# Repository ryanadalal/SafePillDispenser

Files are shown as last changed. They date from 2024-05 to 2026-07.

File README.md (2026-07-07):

# Pill Safety Device

A smart medication dispensing system designed to promote safe, controlled, and responsible medication use. The device combines biometric authentication, scheduled dispensing, and caregiver controls to help ensure medication is taken only by authorized users and at the correct times.

## Overview

Medication adherence is important for both safety and treatment effectiveness. This project provides a secure medication dispenser that uses fingerprint authentication and a real-time clock to enforce dispensing schedules. Caregivers can manage the device through a built-in web interface, allowing them to configure settings, reload medication, and override restrictions when necessary.

The system is intended for situations where a user is capable of taking medication independently but still requires safeguards against missed doses, accidental overdoses, or unauthorized access.

### Features

* Fingerprint authentication to prevent unauthorized access.
* Time-based dispensing using a real-time clock.
* Audible alerts for missed doses and user feedback.
* Wi-Fi connectivity with a built-in web management interface.
* Caregiver override for fingerprint authentication and dispensing schedules.
* Weekly medication reloading and fingerprint management.

## Applications

Possible use cases include:

* Allowing older children to manage medication safely while remaining under caregiver supervision.
* Assisting elderly individuals with medication adherence while enabling caregivers to retain administrative control.
* Any application requiring controlled access to scheduled medication.

## Hardware

### Components

* ESP32 development board
* 2× servo motors
* R30x fingerprint sensor
* Real-time clock (RTC) module
* Arduino-compatible buzzer
* Push button
* Pull-down resistor
* 3D-printed enclosure and internal mechanisms (located in the `cadfiles` folder)

### Schematic

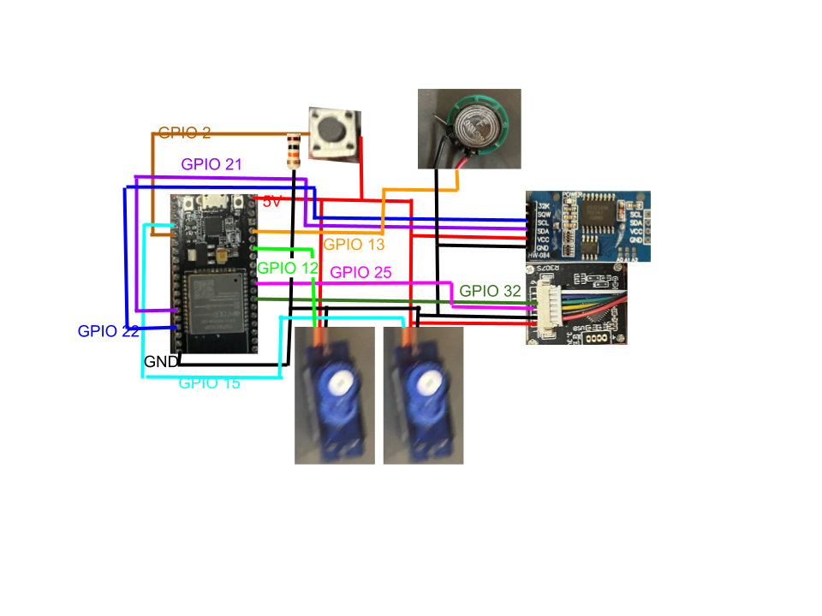
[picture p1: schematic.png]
schematic image


### Photos

#### Complete Assembly

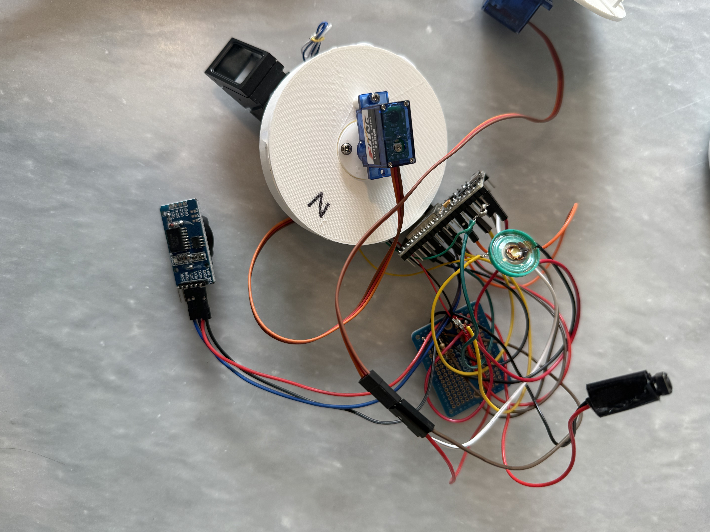
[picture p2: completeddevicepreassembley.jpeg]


#### Rotating Chamber with Integrated Fingerprint Sensor

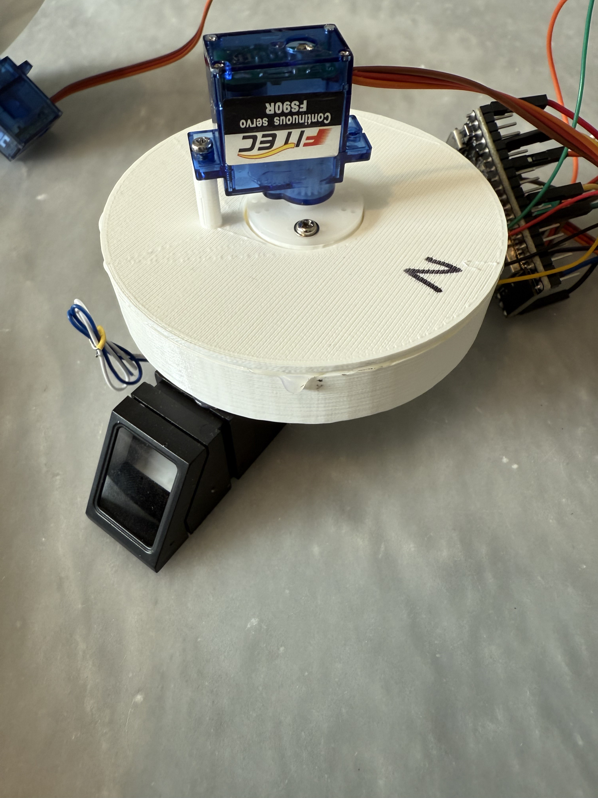
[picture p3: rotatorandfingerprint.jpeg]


#### Internal Sweeper Mechanism

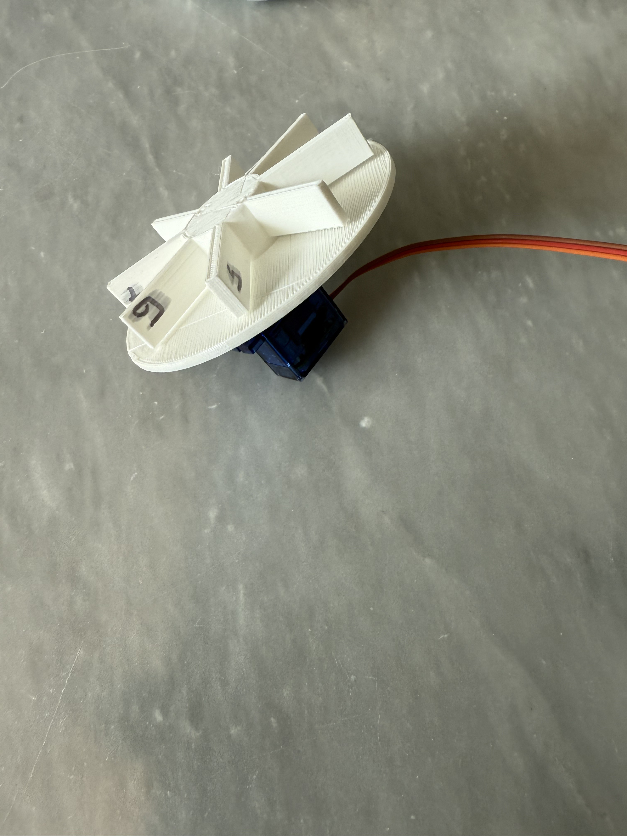
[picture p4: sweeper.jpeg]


## Software

### Project Structure

The primary application is located in:

```text
main/main.ino
```

### Libraries

The project uses the following libraries:

| Library | Purpose |
| --- | --- |
| FPM | Fingerprint sensor communication |
| RTClib | Real-time clock support |
| ESP32Servo | Servo motor control |
| WiFi | Wireless networking |
| ToneESP32 | Buzzer support |
| ESP32 Espressif Board Package | Hardware support and serial communication |

The fingerprint sensor implementation is based on:

https://github.com/brianrho/FPM

### Firmware Architecture

On startup, the ESP32 initializes the hardware peripherals and starts an HTTP server. Rather than serving a single static HTML page, the firmware generates and transmits each page in sections, simplifying maintenance and making it easier to add or modify interface components.

During normal operation, the web server remains largely inactive. User interaction is primarily driven by the push button, which initiates the fingerprint authentication process. Prioritizing local authentication requests ensures responsive dispensing while still allowing remote administration when required.

## Usage

### Normal Operation

1. Press the activation button.
2. Place a finger on the fingerprint sensor.
3. The device verifies the fingerprint.
4. If the authenticated user is a caregiver, dispensing restrictions can be overridden.
5. If the authenticated user is a patient, the firmware checks whether medication is scheduled for the current time.
6. If dispensing is permitted, the servo rotates the appropriate chamber and releases the medication.
7. Audible feedback indicates the result of the operation.

### Caregiver Functions

Using the web interface, a caregiver can:

* Configure device settings.
* Calibrate the dispensing mechanism.
* Reload a new week's supply of medication.
* Override dispensing restrictions when necessary.
* Register or reset caregiver and patient fingerprints.

## Future Improvements

Potential enhancements include:

* Mobile application for remote notifications and management.
* Secure user authentication for the web interface.
* Encrypted communication between the device and management interface.
* Medication logging and dispensing history.
* Battery backup for continued operation during power outages.
* Cloud synchronization and remote monitoring.
* Support for multiple patients or more complex medication schedules.

## License

This project is licensed under the **MIT License**.

Copyright (c) 2026 Ryan Dalal

Permission is hereby granted, free of charge, to any person obtaining a copy
of this software and associated documentation files (the "Software"), to deal
in the Software without restriction, including without limitation the rights
to use, copy, modify, merge, publish, distribute, sublicense, and/or sell
copies of the Software, and to permit persons to whom the Software is
furnished to do so, subject to the following conditions:

The above copyright notice and this permission notice shall be included in all
copies or substantial portions of the Software.

THE SOFTWARE IS PROVIDED "AS IS", WITHOUT WARRANTY OF ANY KIND, EXPRESS OR
IMPLIED, INCLUDING BUT NOT LIMITED TO THE WARRANTIES OF MERCHANTABILITY,
FITNESS FOR A PARTICULAR PURPOSE AND NONINFRINGEMENT. IN NO EVENT SHALL THE
AUTHORS OR COPYRIGHT HOLDERS BE LIABLE FOR ANY CLAIM, DAMAGES OR OTHER
LIABILITY, WHETHER IN AN ACTION OF CONTRACT, TORT OR OTHERWISE, ARISING FROM,
OUT OF OR IN CONNECTION WITH THE SOFTWARE OR THE USE OR OTHER DEALINGS IN THE
SOFTWARE.

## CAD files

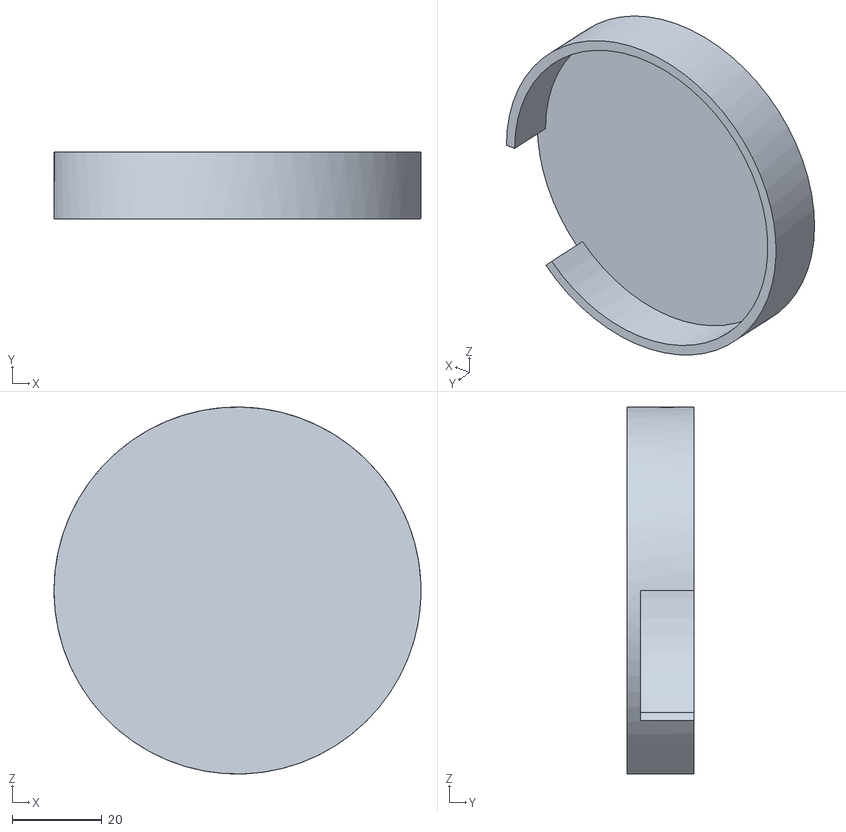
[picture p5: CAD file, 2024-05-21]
cadfiles/mainbody.stl
82.0 x 15.0 x 82.0

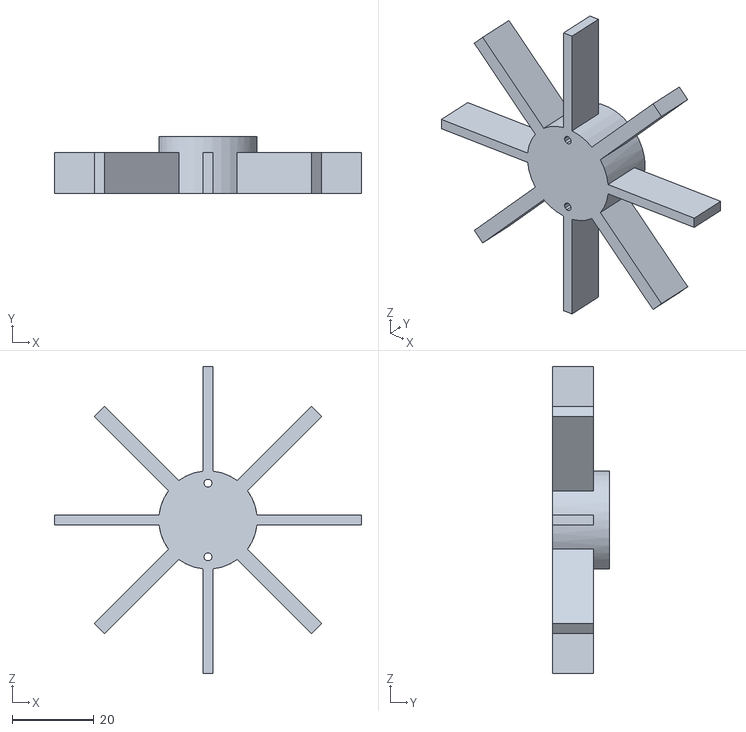
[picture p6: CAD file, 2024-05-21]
cadfiles/sweeper.stl
75.0 x 14.0 x 75.0

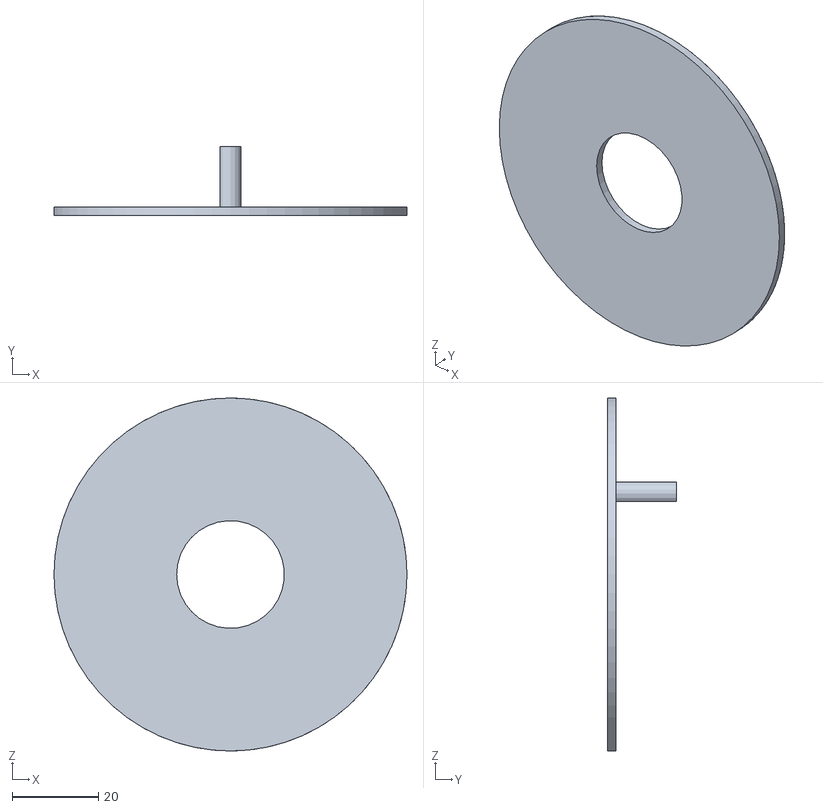
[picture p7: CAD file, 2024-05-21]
cadfiles/lidbetter.stl
82.0 x 16.0 x 82.0

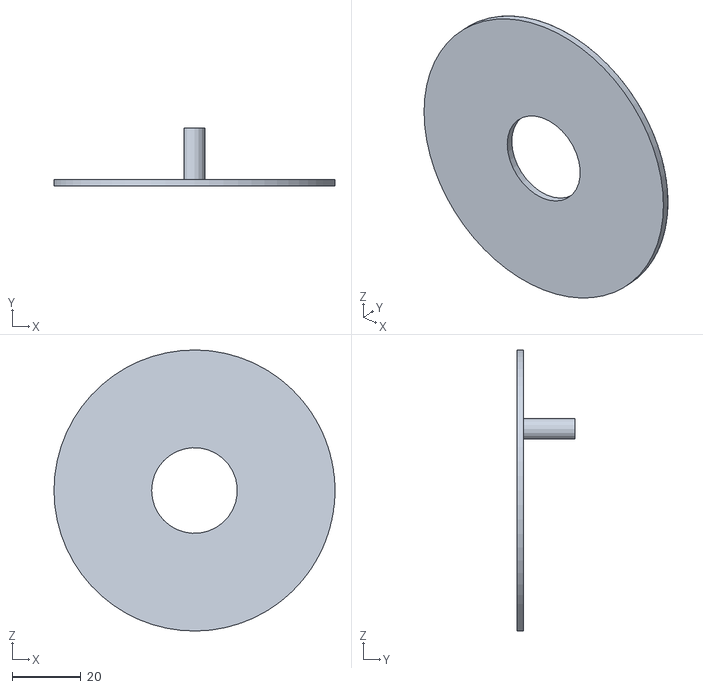
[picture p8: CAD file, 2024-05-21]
cadfiles/lid.stl
82.0 x 17.0 x 82.0

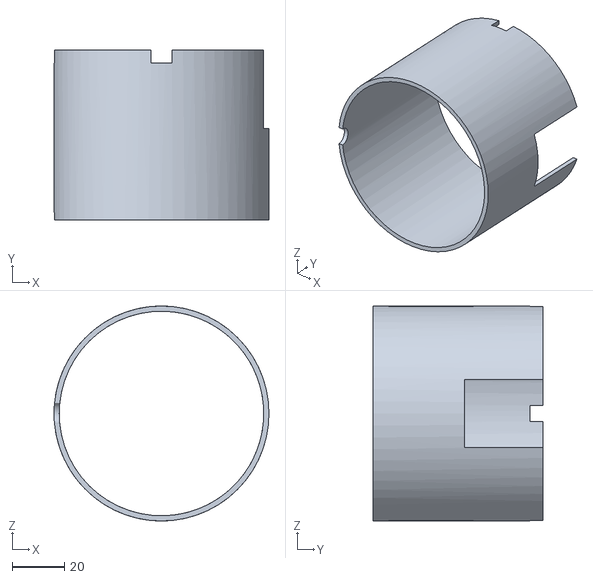
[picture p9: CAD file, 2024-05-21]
cadfiles/case.stl
82.0 x 65.0 x 82.0

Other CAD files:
cadfiles/OldVersions/case.0001.ipt
cadfiles/OldVersions/lid.0002.ipt
cadfiles/OldVersions/mainbody.0003.ipt
cadfiles/OldVersions/sweeper.0001.ipt
cadfiles/case.ipt
cadfiles/lid.ipt
cadfiles/lidbetter.ipt
cadfiles/mainbody.ipt
cadfiles/sweeper.ipt

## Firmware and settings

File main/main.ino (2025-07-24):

// comments designate arudion library manager names
#include <Wire.h>
#include <RTClib.h>         // rtclib
#include <ESP32Servo.h>     // esp32servo
#include <HardwareSerial.h> // esp espressif board
#include <fpm.h>            // FPM github
#include <WiFi.h>
#include <ToneESP32.h> // toneesp32

/*
In assembling the physical device:
- clock uses pins 21 and 22
- servo uses pin 15 and 0
- finger print uses pins 25 TX, 32 RX
- speaker red uses pin 13
- button is pin 2
*/

#define PRINTF_BUFFER_SIZE 40

// network credentials
const char *ssid = "FILL_IN_NETWORK_NAME";
const char *password = "PASSWORD";

// Set web server port number to 80
WiFiServer server(80);
String header; // for storing HTTP requests
WiFiClient client;

// timings used to check for disconnections
unsigned long tPresent = millis();
unsigned long tPast = 0;
const long maxTime = 4000;

RTC_DS3231 rtc;

Servo servoTop;
Servo servoBottom;
// rotational position of the servers in day of the week
int servoTopPosition = -1;
int servoBottomPosition = -1;

const int checkFingerButtonPin = 2;
int checkFingerButtonState = 0;

// set up the buzzer
ToneESP32 buzzer(13, 5);

HardwareSerial fserial(1);
FPM finger(&fserial);
FPMSystemParams params;

char printfBuf[PRINTF_BUFFER_SIZE];

void setup()
{
  Serial.begin(57600);
  Serial.println("Safe Pill Dispenser");

  // initialize the clock
  rtc.begin();
  Serial.println(getDateString());

  // assign servo motors
  servoTop.attach(15);
  servoBottom.attach(12);

  // prepare for finger print input
  pinMode(checkFingerButtonPin, INPUT);

  // connect wifi
  Serial.print("Connecting to ");
  Serial.println(ssid);
  WiFi.begin(ssid, password);
  // waits for wifi to connect
  while (WiFi.status() != WL_CONNECTED)
  {
    delay(500);
    Serial.print(".");
  }
  // prints the devices ip address
  Serial.println("");
  Serial.println("wifi connection success");
  Serial.println("ip address: ");
  Serial.println(WiFi.localIP());
  server.begin();

  // initiates hardware serial for fingerprint reader
  fserial.begin(57600, SERIAL_8N1, 25, 32);

  // attempt to initiate the finger print sensor
  if (finger.begin())
  {

    finger.readParams(&params);
    Serial.println("found finger print sensor with capacity ");
    Serial.println(params.capacity);
    Serial.println(" and packet length ") ;
    Serial.println(FPM::packetLengths[static_cast<uint8_t>(params.packetLen)]);
  }
  else
  {
    Serial.println("failed to find finger print sensor");
    exit(0);
  }
}

void loop()
{
  // checks the current time
  DateTime rtcTime = rtc.now();

  // plays error noises if the positions are incorrect
  if (servoBottomPosition == -1 || servoTopPosition == -1)
  {
    buzzer.tone(NOTE_FS7, 250);
    buzzer.tone(NOTE_C7, 250);
  }
  else
  {
    // checks if the user wants to verify a finger print
    checkFingerButtonState = digitalRead(checkFingerButtonPin);
    if (checkFingerButtonState == 1)
    {
      // checks if the fingerprint is a valid print
      int searchFinger = searchDatabase();
      if (searchFinger != 0)
      {
        // plays a positive tone
        buzzer.tone(NOTE_E7, 120);
        buzzer.tone(NOTE_E7, 120);
        delay(120);
        buzzer.tone(NOTE_E7, 120);
        delay(120);
        buzzer.tone(NOTE_C7, 120);
        buzzer.tone(NOTE_E7, 120);
        // rotates the device if the timing is correct
        checkAndRotate(searchFinger);
      }
      else
      {
        // plays error tone
        buzzer.tone(NOTE_CS6, 62);
        buzzer.tone(NOTE_CS7, 62);
        buzzer.tone(NOTE_C7, 375);
        buzzer.tone(NOTE_GS6, 62);
        buzzer.tone(NOTE_FS6, 62);
        buzzer.tone(NOTE_GS6, 375);
      }
      while (Serial.read() != -1)
        ;
    }
  }

  // check for a web client connetion
  client = server.available();
  if (client)
  {
    // variables used for time out checks
    tPresent = millis();
    tPast = tPresent;
    Serial.println("new client connection");
    // initializes incoming client request storage
    String currentLine = "";
    // ensures the client has not been lost
    while (client.connected() && tPresent - tPast <= maxTime)
    {
      tPresent = millis();
      // checks for incoming requests prints and then handles them
      if (client.available())
      {
        char c = client.read();
        Serial.write(c);
        header += c;
        if (c == '\n')
        {
          // send a response if the client has finished sending requests
          if (currentLine.length() == 0)
          {
            // return the base html for the webpage
            client.println("HTTP/1.1 200 OK");
            client.println("Content-type:text/html");
            client.println("Connection: close");
            client.println("<!DOCTYPE html><html>");
            client.println("<head><meta name=\"viewport\" content=\"width=device-width, initial-scale=1\">");
            client.println("<link rel=\"icon\" href=\"data:,\">");
            client.println("<style>");
            client.println("html { display: inline-block; margin: 0px auto; text-align: center;}");
            client.println(".button { margin: 2px; background-color: #FF0000; padding: 15px 30px; color: white; }");
            client.println(".button2 {background-color: #0000AA;}");
            client.println("</style>");
            client.println("</head>");

            // handler for a new request from the client

            // on user says calibratoin complete
            if (header.indexOf("GET /calibrate/done") >= 0)
            {
              Serial.println("Done Calibrating");
              servoTopPosition = 0;
              servoBottomPosition = 0;
            }
            // user currently calibrating top or bottom
            if (servoTopPosition == -1 || servoBottomPosition == -1)
            {
              // on user adjusting the rotation of the top or bottom
              if (header.indexOf("GET /calibrate/top") >= 0)
              {
                Serial.println("Rotating top by one slot");
                rotateTop(false);
              }
              if (header.indexOf("GET /calibrate/bottom") >= 0)
              {
                Serial.println("Rotating bottom by one slot");
                rotateBottom(false);
              }

              // begin transmitting the rest of the html page for recalbiration
              client.println("<body>");
              client.println("<h1>Recalibration Needed!</h1>");

              // outputs the time to the user
              client.print("<p>");
              client.print(getDateString());
              client.println("</p>");

              client.println("<h2>Please rotate each capsule until the blank day is visible, when you are finished select -Done Calibrating-</h2>");

              // buttons for the user to press for calibration
              client.println("<p><a href=\"/calibrate/top\"><button class=\"button\">Rotate Top (rotates one slot over) </button></a></p>");
              client.println("<p><a href=\"/calibrate/bottom\"><button class=\"button\">Rotate Bottom (rotates one slot over) </button></a></p>");
              client.println("<p><a href=\"/calibrate/done\"><button class=\"button\">Done Calibrating</button></a></p>");
            }
            // on user request to reset the parent fingerprint
            else if (header.indexOf("GET /finger/resetparent") >= 0)
            {
              Serial.println("Reseting Parent Finger");
              enrollFinger(1);
            }
            // on user request to reset the child fingerprint
            else if (header.indexOf("GET /finger/resetchild") >= 0)
            {
              Serial.println("Reseting Child Finger");
              enrollFinger(2);
            }
            else
            {
              // on user refilling the top - manually rotating
              if (header.indexOf("GET /refill/top") >= 0)
              {
                Serial.println("Rotating top by one slot");
                rotateTop(true);
              }
              // on user refilling the bottom - manually rotating
              if (header.indexOf("GET /refill/bottom") >= 0)
              {
                Serial.println("Rotating bottom by one slot");
                rotateBottom(true);
              }

              // standard home page
              client.println("<body>");
              client.println("<h1>Safe Pills</h1>");

              // time
              client.print("<p>");
              client.print(getDateString());
              client.println("</p>");

              // button options
              client.println("<h2>Reset finger prints</h2>");
              client.println("<p><a href=\"/finger/resetparent\"><button class=\"button\">Reset Parent Finger</button></a></p>");
              client.println("<p><a href=\"/finger/resetchild\"><button class=\"button\">Reset Child Finger</button></a></p>");

              client.println("<h2>Refill</h2>");
              client.println("<p><a href=\"/refill/top\"><button class=\"button\">Refill Top (rotates one slot over) </button></a></p>");
              client.println("<p><a href=\"/refill/bottom\"><button class=\"button\">Refill Bottom (rotates one slot over) </button></a></p>");
            }
            client.println("</body></html>");

            // end the response
            client.println();

            break;
          }
          else
          {
            // reset
            currentLine = "";
          }
        }
        // add any non returns to the end of the current line
        else if (c != '\r')
        {
          currentLine += c;
        }
      }
    }
    // clear the header and close the connection
    header = "";
    client.stop();
    Serial.println("Client disconnected.");
    Serial.println("");
  }
  else
  {
    // play a tune if the pill was forgotten
    DateTime rtcTime = rtc.now();
    int dow = rtcTime.dayOfTheWeek();
    if (dow == servoTopPosition && rtcTime.hour() > 10 || dow == servoBottomPosition && rtcTime.hour() > 22)
    {
      buzzer.tone(NOTE_A4, 500);
      buzzer.tone(NOTE_A4, 500);
      buzzer.tone(NOTE_A4, 500);
      buzzer.tone(NOTE_F4, 350);
      buzzer.tone(NOTE_C5, 150);
      buzzer.tone(NOTE_A4, 500);
      buzzer.tone(NOTE_F4, 350);
      buzzer.tone(NOTE_C5, 150);
      buzzer.tone(NOTE_A4, 650);
      delay(500);
      buzzer.tone(NOTE_E5, 500);
      buzzer.tone(NOTE_E5, 500);
      buzzer.tone(NOTE_E5, 500);
      buzzer.tone(NOTE_F5, 350);
      buzzer.tone(NOTE_C5, 150);
      buzzer.tone(NOTE_GS4, 500);
      buzzer.tone(NOTE_F4, 350);
      buzzer.tone(NOTE_C5, 150);
      buzzer.tone(NOTE_A4, 650);
    }
  }
}

/*
 * gets the time from the real time clock module
 * returns - date and time in a human readable form
 */
String getDateString()
{
  DateTime rtcTime = rtc.now();
  String result = "Current Date Time: ";
  result += rtcTime.month();
  result += '/';
  result += rtcTime.day();
  result += '/';
  result += rtcTime.year();
  result += " ";
  int dow = rtcTime.dayOfTheWeek();
  switch (dow)
  {
  case 0:
    result += "Sunday";
    break;
  case 1:
    result += "Monday";
    break;
  case 2:
    result += "Tuesday";
    break;
  case 3:
    result += "Wednesday";
    break;
  case 4:
    result += "Thursday";
    break;
  case 5:
    result += "Friday";
    break;
  case 6:
    result += "Saturday";
    break;
  }
  result += " ";
  result += rtcTime.hour();
  result += ':';
  result += rtcTime.minute();
  result += ':';
  result += rtcTime.second();
  return result;
}

// rotations for the top and bottom servos
void rotateTop(bool changePosition)
{
  servoTop.writeMicroseconds(1600);
  delay(120);
  servoTop.writeMicroseconds(1500);
  if (changePosition)
  {
    servoTopPosition += 1;
  }
  if (servoTopPosition == 8)
  {
    servoTopPosition = 0;
  }
}
void rotateBottom(bool changePosition)
{
  servoBottom.writeMicroseconds(1600);
  delay(200);
  servoBottom.writeMicroseconds(1500);
  if (changePosition)
  {
    servoBottomPosition += 1;
  }
  if (servoBottomPosition == 8)
  {
    servoBottomPosition = 0;
  }
}

// checks if device should rotate
void checkAndRotate(int id)
{
  // allows the parent to override and rotate if the child misses a pill
  if (id == 1)
  {
    DateTime rtcTime = rtc.now();
    int dow = rtcTime.dayOfTheWeek();
    if (dow == servoTopPosition)
    {
      if ((rtcTime.hour() > 3 && rtcTime.hour() < 14))
      {
        rotateTop(true);
      }
    }
    if (dow == servoBottomPosition)
    {
      if ((rtcTime.hour() > 14 || rtcTime.hour() < 3))
      {
        rotateBottom(true);
      }
    }
  }
  // rotates if the timing is right
  else if (id == 2)
  {
    DateTime rtcTime = rtc.now();
    int dow = rtcTime.dayOfTheWeek();
    if (dow == servoTopPosition)
    {
      if ((rtcTime.hour() > 6 && rtcTime.hour() < 10))
      {
        rotateTop(true);
      }
    }
    if (dow == servoBottomPosition)
    {
      if ((rtcTime.hour() > 18 && rtcTime.hour() < 22))
      {
        rotateBottom(true);
      }
    }
  }
}

// prints the html for refilling the capsules
void refillCapsules(int day)
{
  client.println("<body>");
  client.println("<h1>Capsule Refills</h1>");
  client.println("<p>Click the button to rotate the device by one day, and when you are done after returning the device to the empty slot click done</p>");
}

// enrolls new finger prints
bool enrollFinger(int16_t fid)
{
  client.println("<body>");
  client.println("<h1>Enrolling Finger</h1>");
  if (fid == 1)
  {
    client.println("<p>This is for the parents</p>");
  }
  else if (fid == 2)
  {
    client.println("<p>This is for the child</p>");
  }

  // credit: finger print module code uses example code from https://github.com/brianrho/FPM
  FPMStatus status;
  const int NUM_SNAPSHOTS = 2;

#if defined(FPM_LED_CONTROL_ENABLED)
  finger.ledOn();
#endif

  /* Take snapshots of the finger,
   * and extract the fingerprint features from each image */
  for (int i = 0; i < NUM_SNAPSHOTS; i++)
  {
    Serial.println(i == 0 ? "Place a finger" : "Place same finger again");
    client.println(i == 0 ? "<p>Place a finger</p>" : "<p>Place same finger again</p>");

    do
    {
#if defined(FPM_LED_CONTROL_ENABLED)
      status = finger.getImageOnly();
#else
      status = finger.getImage();
#endif

      switch (status)
      {
      case FPMStatus::OK:
        Serial.println("Image taken");
        client.println("<p>Image taken</p>");
        break;

      case FPMStatus::NOFINGER:
        Serial.print(".");
        break;

      default:
        /* allow retries even when an error happens */
        snprintf(printfBuf, PRINTF_BUFFER_SIZE, "getImage(): error 0x%X", static_cast<uint16_t>(status));
        Serial.println(printfBuf);
        break;
      }

      yield();
    } while (status != FPMStatus::OK);

    status = finger.image2Tz(i + 1);

    switch (status)
    {
    case FPMStatus::OK:
      Serial.println("Image converted");
      client.println("<p>Image Converted</p>");
      break;

    default:
      snprintf(printfBuf, PRINTF_BUFFER_SIZE, "image2Tz(%d): error 0x%X", i + 1, static_cast<uint16_t>(status));
      Serial.println(printfBuf);
      client.println("<p>Error! Please try again later</p>");
      client.println("<p><a href=\"/\"><button class=\"button\">Return home</button></a></p>");
      return false;
    }

    Serial.println("Remove finger");
    client.println("<p>Remove finger</p>");
    delay(1000);
    do
    {
#if defined(FPM_LED_CONTROL_ENABLED)
      status = finger.getImageOnly();
#else
      status = finger.getImage();
#endif
      delay(200);
    } while (status != FPMStatus::NOFINGER);
  }

#if defined(FPM_LED_CONTROL_ENABLED)
  finger.ledOff();
#endif

  /* Images have been taken and converted into features a.k.a character files.
   * Now, need to create a model/template from these features and store it. */

  status = finger.generateTemplate();
  switch (status)
  {
  case FPMStatus::OK:
    Serial.println("Template created from matching prints!");
    client.println("<p>Template Created from matching prints!</p>");
    break;

  case FPMStatus::ENROLLMISMATCH:
    Serial.println("The prints do not match!");
    client.println("<p>The prints do not match, try again later!</p>");
    client.println("<p><a href=\"/\"><button class=\"button\">Return home</button></a></p>");
    return false;

  default:
    snprintf(printfBuf, PRINTF_BUFFER_SIZE, "createModel(): error 0x%X", static_cast<uint16_t>(status));
    Serial.println(printfBuf);
    client.println("<p>Error! Please try again later</p>");
    client.println("<p><a href=\"/\"><button class=\"button\">Return home</button></a></p>");
    return false;
  }

  status = finger.storeTemplate(fid);
  switch (status)
  {
  case FPMStatus::OK:
    snprintf(printfBuf, PRINTF_BUFFER_SIZE, "Template stored at ID %d!", fid);
    Serial.println(printfBuf);
    client.println("<p>Fingerprint successfully stored</p>");
    break;

  case FPMStatus::BADLOCATION:
    snprintf(printfBuf, PRINTF_BUFFER_SIZE, "Could not store in that location %d!", fid);
    Serial.println(printfBuf);
    client.println("<p>Error! Please try again later</p>");
    client.println("<p><a href=\"/\"><button class=\"button\">Return home</button></a></p>");
    return false;

  default:
    snprintf(printfBuf, PRINTF_BUFFER_SIZE, "storeModel(): error 0x%X", static_cast<uint16_t>(status));
    Serial.println(printfBuf);
    client.println("<p>Error! Please try again later</p>");
    client.println("<p><a href=\"/\"><button class=\"button\">Return home</button></a></p>");
    return false;
  }
  client.println("<p><a href=\"/\"><button class=\"button\">Return home</button></a></p>");
  return true;
}

//
// FIND IF THIS FINGER IS A MATCH TO ONE IN THE DATABASE
//
int searchDatabase(void)
{
  FPMStatus status;

  /* Take a snapshot of the input finger */
  Serial.println("Place a finger.");

  do
  {
    status = finger.getImage();

    switch (status)
    {
    case FPMStatus::OK:
      Serial.println("Image taken");
      break;

    case FPMStatus::NOFINGER:
      Serial.println(".");
      break;

    default:
      /* allow retries even when an error happens */
      snprintf(printfBuf, PRINTF_BUFFER_SIZE, "getImage(): error 0x%X", static_cast<uint16_t>(status));
      Serial.println(printfBuf);
      break;
    }

    yield();
  } while (status != FPMStatus::OK);

  /* Extract the fingerprint features */
  status = finger.image2Tz();

  switch (status)
  {
  case FPMStatus::OK:
    Serial.println("Image converted");
    break;

  default:
    snprintf(printfBuf, PRINTF_BUFFER_SIZE, "image2Tz(): error 0x%X", static_cast<uint16_t>(status));
    Serial.println(printfBuf);
    return false;
  }

  /* Search the database for the converted print */
  uint16_t fid, score;
  status = finger.searchDatabase(&fid, &score);

  switch (status)
  {
  case FPMStatus::OK:
    snprintf(printfBuf, PRINTF_BUFFER_SIZE, "Found a match at ID #%u with confidence %u", fid, score);
    Serial.println(printfBuf);
    Serial.println((fid == 1) ? "parents" : "child");
    break;

  case FPMStatus::NOTFOUND:
    Serial.println("Did not find a match.");
    return 0;

  default:
    snprintf(printfBuf, PRINTF_BUFFER_SIZE, "searchDatabase(): error 0x%X", static_cast<uint16_t>(status));
    Serial.println(printfBuf);
    return 0;
  }

  /* Now wait for the finger to be removed, though not necessary.
     This was moved here after the Search operation because of the R503 sensor,
     whose searches oddly fail if they happen after the image buffer is cleared  */
  Serial.println("Remove finger.");
  delay(1000);
  do
  {
    status = finger.getImage();
    delay(200);
  } while (status != FPMStatus::NOFINGER);

  return fid;
}
// end of credit

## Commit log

2025-07-24 restructured files
    [case.0001.ipt, case.ipt, case.stl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]
2025-07-24 last working version
    [case.0001.ipt, case.ipt, case.stl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]
2026-07-07 Enhance README with detailed project overview
    Expanded the README to provide a comprehensive overview of the Pill Safety Device, detailing its features, applications, hardware, software, and future improvements.
